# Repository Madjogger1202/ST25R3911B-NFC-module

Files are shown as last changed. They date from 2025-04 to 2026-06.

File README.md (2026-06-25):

# ST25R3911B-NFC-module

**NFC-модуль на высокопроизводительном HF-ридере ST25R3911B с управлением от RP2040 и антенной на плате.**

Плата NFC-ридера на чипе **ST25R3911B** (STMicroelectronics) — это заметно более функциональное решение, чем популярные бюджетные модули (PN532, RC522): высокая выходная мощность, поддержка VHBR, автоматическая подстройка антенны и ёмкостный wake-up. Логику и интерфейс берёт на себя **RP2040**, антенна разведена прямо на плате с соблюдением всех рекомендаций ST по согласующим и фильтрующим цепям. После отладки модуль можно смело переиспользовать как ВЧ-фронтенд в составе больших систем.

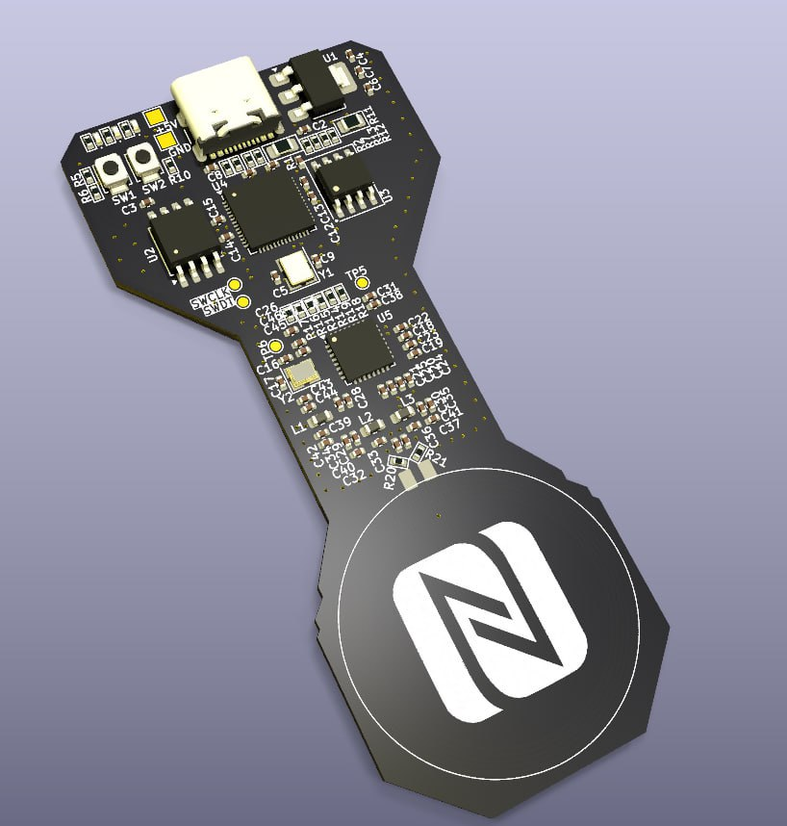
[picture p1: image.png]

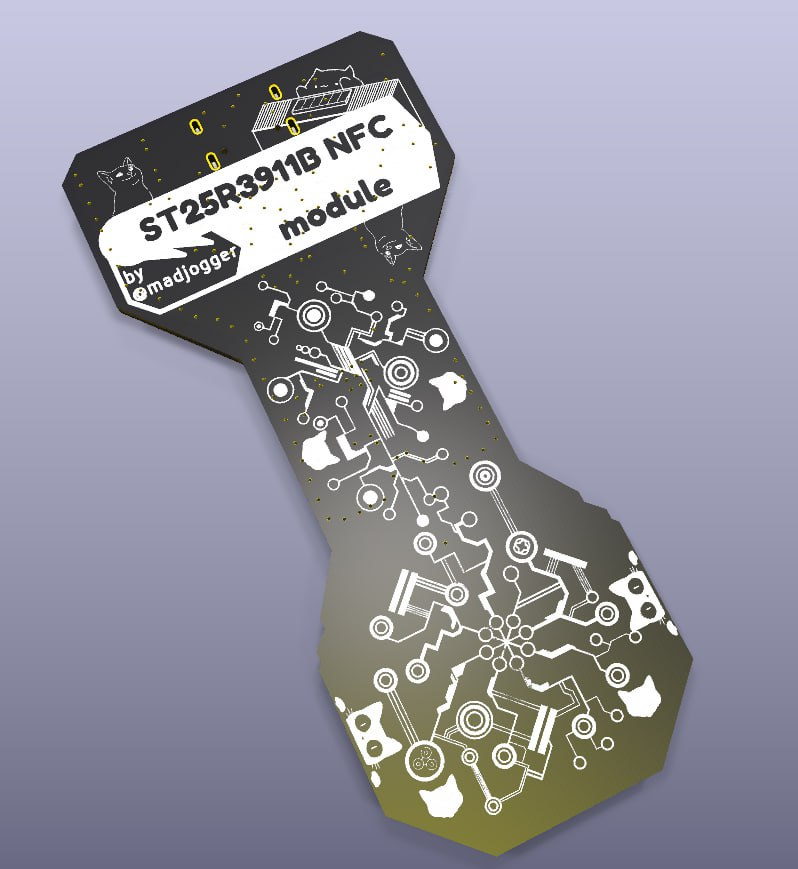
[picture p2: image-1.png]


## Обзор

- **Название проекта:** ST25R3911B-NFC-module
- **Ридер:** STMicroelectronics ST25R3911B — высокопроизводительный HF reader / NFC initiator (13.56 МГц)
- **Микроконтроллер:** Raspberry Pi RP2040
- **Интерфейс ридер ↔ МК:** SPI
- **Антенна:** на плате, с согласующими и фильтрующими цепями по рекомендациям ST
- **Назначение:** отладка ST25R3911B и использование как ВЧ-фронтенда в больших системах

## Ключевые особенности

- **Мультипротокольный HF-ридер** — ISO14443A, ISO14443B (включая высокие битрейты / VHBR), ISO15693, ISO18092 (NFCIP-1, инициатор и активная цель), FeliCa; MIFARE Classic через AFE и framing на стороне МК
- **Высокая выходная мощность** — до 1.4 Вт, два дифференциальных низкоомных (1 Ω) драйвера антенны → большая дальность считывания
- **Автоматическая подстройка антенны (AAT)** — оптимизация под напрямую подключённую антенну
- **Ёмкостный wake-up** — детектирование присутствия карты без включения ВЧ-поля (низкое энергопотребление), плюс детект по амплитуде/фазе
- **Встроенный АЦП** — измерение амплитуды и фазы сигнала на антенне, калибровка
- **Антенна на плате** — разведена с соблюдением рекомендаций ST по фильтрам и согласованию
- **Управление от RP2040** — двухъядерный Cortex-M0+ для логики и обработки

## Что на плате

| Блок | Компонент | Назначение |
|---|---|---|
| NFC-ридер | ST25R3911B | HF reader / NFC initiator, 13.56 МГц |
| Микроконтроллер | RP2040 | Управление, обработка, интерфейс с хостом |
| Антенна | PCB-антенна | Дифференциальная антенна на плате |
| Согласование/фильтры | EMC-фильтр + matching | Цепи по рекомендациям ST (AAT) |
| Интерфейс | USB | Питание и связь с хостом |

## Технические характеристики

| Параметр | Значение |
|---|---|
| Ридер | STMicroelectronics ST25R3911B |
| Рабочая частота | 13.56 МГц |
| Протоколы | ISO14443A/B (+VHBR), ISO15693, ISO18092 (NFCIP-1), FeliCa |
| Выходная мощность | до 1.4 Вт (дифференциальная антенна) |
| Драйверы антенны | 2× дифференциальные, 1 Ω |
| Доп. функции | AAT, ёмкостный wake-up, встроенный АЦП |
| Интерфейс ридера | SPI |
| Микроконтроллер | RP2040, 2× Cortex-M0+ до 133 МГц |
| Питание ридера | 2.4 … 5.5 В |

## Антенна

Антенна выполнена непосредственно на печатной плате. Согласующие и фильтрующие цепи (EMC-фильтр между драйвером и антенной, цепи подстройки) разведены с соблюдением рекомендаций STMicroelectronics, что в связке с автоматической подстройкой антенны (AAT) обеспечивает стабильную работу ВЧ-тракта.

## Применение

- Считыватель карт и меток NFC/RFID (контроль доступа, тикетинг)
- ВЧ-фронтенд для интеграции в большие системы
- Отладка и изучение многопротокольного NFC-ридинга
- Промышленные, медицинские и потребительские NFC-приложения

## Среда разработки

- **Схема и плата:** KiCad
- **Прошивка:** PlatformIO / Arduino / Pico SDK (RP2040), драйвер ST25R3911B (ST RFAL)
- **Документация на компоненты:** datasheet ST25R3911B (ST), RP2040 (Raspberry Pi)

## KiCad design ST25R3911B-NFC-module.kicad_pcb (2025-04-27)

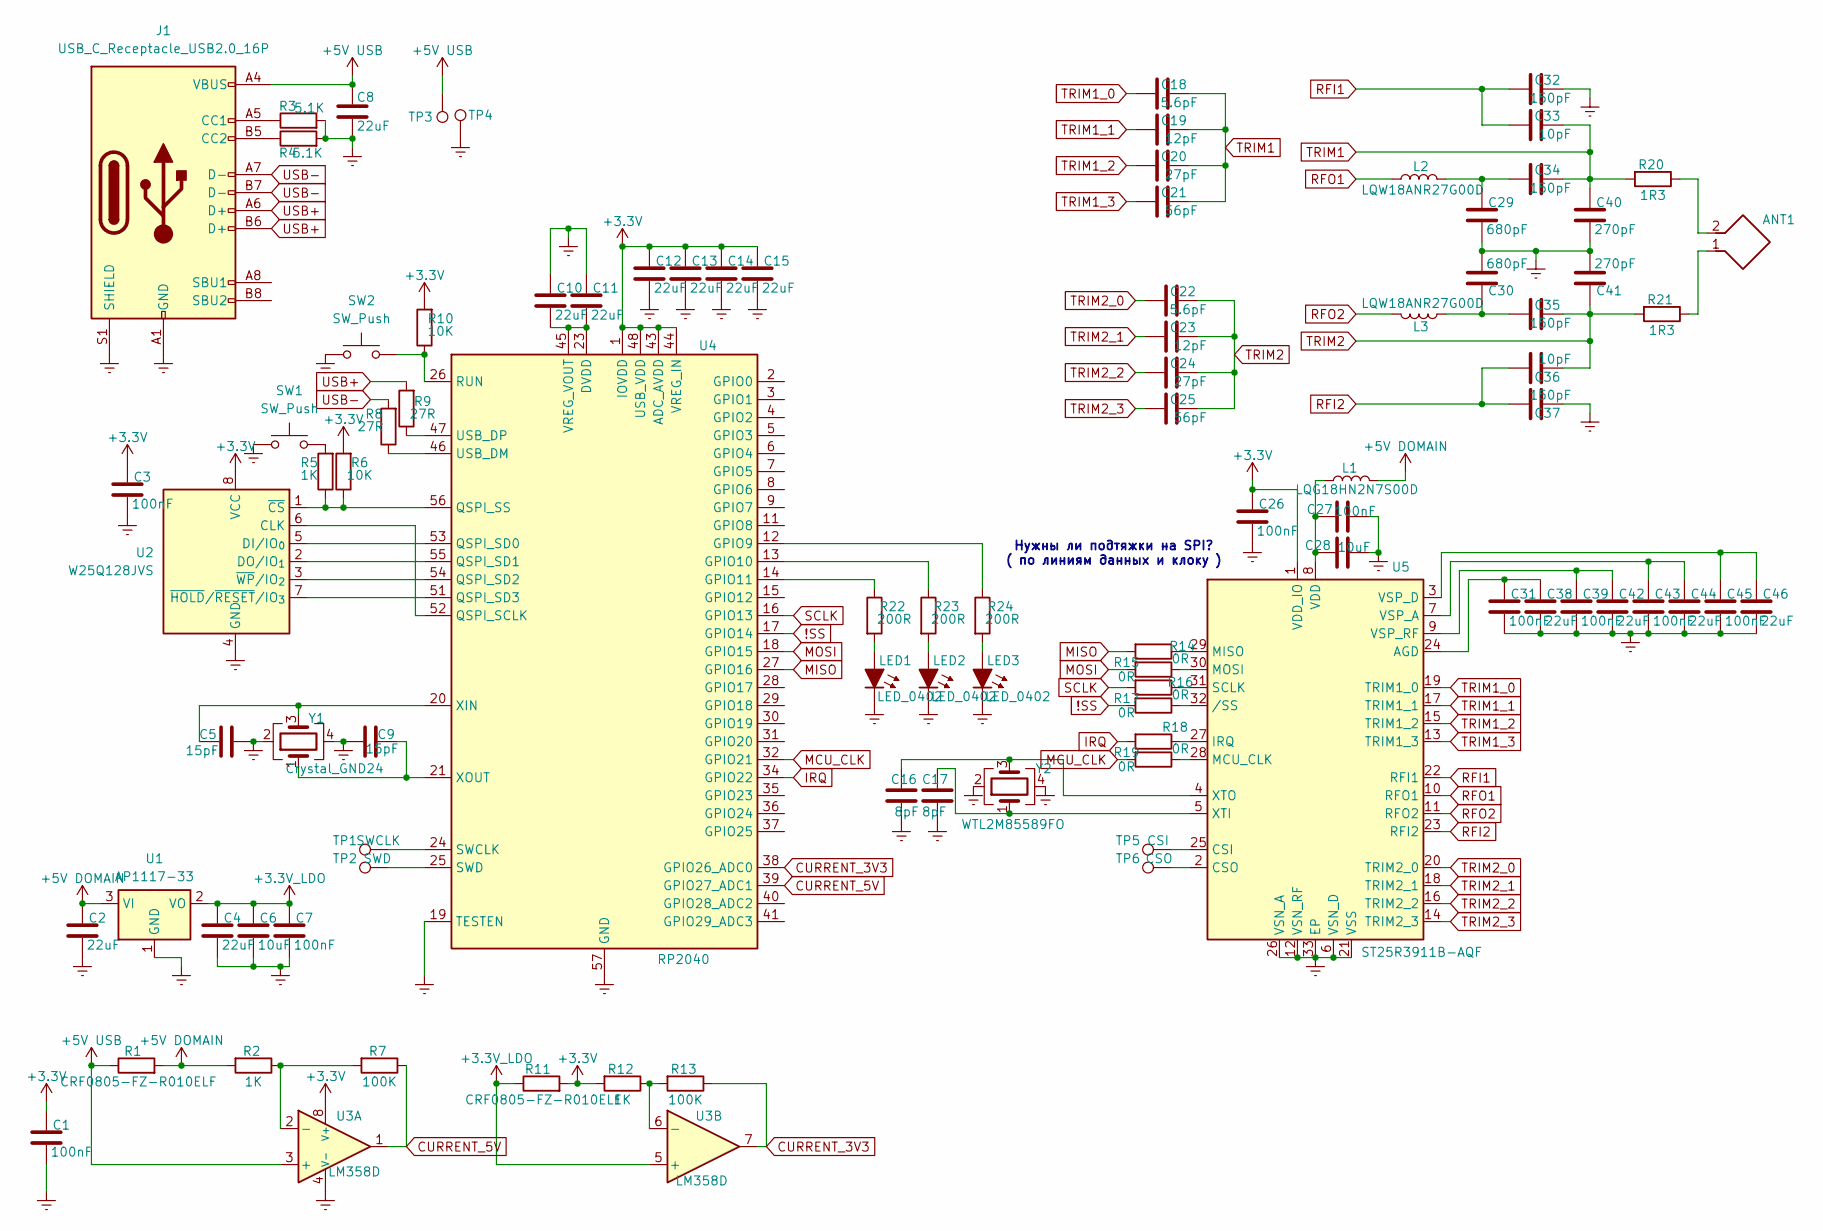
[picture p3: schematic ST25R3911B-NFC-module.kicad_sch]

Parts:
ANT1: Без имени
C1, C3, C7, C26, C27, C31, C39, C43, C45: 100nF; C_0402_1005Metric
C2, C4, C8, C10, C11, C12, C13, C14, C15, C38, C42, C44, C46: 22uF; C_0402_1005Metric
C5, C9: 15pF; C_0402_1005Metric
C6, C28: 10uF; C_0402_1005Metric
C16, C17: 8pF; C_0402_1005Metric
C18, C22: 5.6pF; C_0402_1005Metric
C19, C23: 12pF; C_0402_1005Metric
C20, C24: 27pF; C_0402_1005Metric
C21, C25: 56pF; C_0402_1005Metric
C29, C30: 680pF; C_0402_1005Metric
C32, C34, C35, C37: 150pF; C_0402_1005Metric
C33, C36: 10pF; C_0402_1005Metric
C40, C41: 270pF; C_0402_1005Metric
J1: USB_C_Receptacle_USB2.0_16P; USB_C_Receptacle_GCT_USB4105-xx-A_16P_TopMnt_Horizontal
L1: LQG18HN2N7S00D; L_0603_1608Metric
L2, L3: LQW18ANR27G00D; L_0603_1608Metric
LED1, LED2, LED3: LED_0402; LED_0402_1005Metric
R1: CRF0805-FZ-R010ELF; R_0805_2012Metric_Pad1.15x1.40mm
R2, R5, R12: 1K; R_0402_1005Metric
R3, R4: 5.1K; R_0402_1005Metric
R6, R10: 10K; R_0402_1005Metric
R7, R13: 100K; R_0402_1005Metric
R8, R9: 27R; R_0402_1005Metric
R11: CRF0805-FZ-R010ELF; R_0805_2012Metric
R14, R15, R16, R17, R18, R19: 0R; R_0402_1005Metric
R20, R21: 1R3; R_0402_1005Metric
R22, R23, R24: 200R; R_0402_1005Metric
SW1, SW2: SW_Push; SW_SPST_B3U-1000P
TP1: SWCLK; TestPoint_Pad_D1.0mm
TP2: SWD; TestPoint_Pad_D1.0mm
TP3, TP4: TestPoint_Pad_1.5x1.5mm
TP5: CSI; TestPoint_Pad_D1.0mm
TP6: CSO; TestPoint_Pad_D1.0mm
U1: AP1117-33; SOT-223-3_TabPin2
U2: W25Q128JVS; SOIC-8_5.3x5.3mm_P1.27mm
U3: LM358D; SO-8_3.9x4.9mm_P1.27mm
U4: RP2040; QFN-56-1EP_7x7mm_P0.4mm_EP3.2x3.2mm
U5: ST25R3911B-AQF; QFN-32-1EP_5x5mm_P0.5mm_EP3.6x3.6mm_ThermalVias
Y1: Crystal_GND24; Crystal_SMD_Abracon_ABM8G-4Pin_3.2x2.5mm
Y2: WTL2M85589FO; Crystal_SMD_2520-4Pin_2.5x2.0mm

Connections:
!SS: R17.2, U4.17 (GPIO14)
+3.3V: C1.1, C3.1, C12.1, C13.1, C14.1, C15.1, C26.1, R6.2, R10.2, R11.2, R12.2, U2.8 (VCC), U3.8 (V+), U4.1 (IOVDD), U4.10 (IOVDD), U4.22 (IOVDD), U4.33 (IOVDD), U4.42 (IOVDD), U4.43 (ADC_AVDD), U4.44 (VREG_IN), U4.48 (USB_VDD), U4.49 (IOVDD), U5.1 (VDD_IO)
+3.3V_LDO: C4.1, C6.1, C7.1, R11.1, U1.2 (VO), U3.5 (+)
+5V DOMAIN: C2.1, L1.1, R1.2, R2.2, U1.3 (VI)
+5V USB: C8.1, J1.A4 (VBUS), J1.A9 (VBUS), J1.B4 (VBUS), J1.B9 (VBUS), R1.1, TP3.1, U3.3 (+)
CURRENT_3V3: R13.1, U3.7, U4.38 (GPIO26_ADC0)
CURRENT_5V: R7.1, U3.1, U4.39 (GPIO27_ADC1)
Earth: C1.2, C2.2, C3.2, C4.2, C5.2, C6.2, C7.2, C8.2, C9.1, C10.1, C11.1, C12.2, C13.2, C14.2, C15.2, C16.1, C17.2, C26.2, C27.2, C28.2, C29.2, C30.2, C31.2, C32.2, C37.2, C38.2, C39.2, C40.2, C41.2, C42.2, C43.2, C44.2, C45.2, C46.2, J1.A1 (GND), J1.A12 (GND), J1.B1 (GND), J1.B12 (GND), J1.S1 (SHIELD), LED1.1 (K), LED2.1 (K), LED3.1 (K), R3.2, R4.2, SW1.1, SW2.1, TP4.1, U1.1 (GND), U2.4 (GND), U3.4 (V-), U4.19 (TESTEN), U4.57 (GND), U5.6 (VSN_D), U5.12 (VSN_RF), U5.21 (VSS), U5.26 (VSN_A), U5.33 (EP), Y1.2, Y1.4, Y2.2, Y2.4
IRQ: R18.2, U4.34 (GPIO22)
MCU_CLK: R19.2, U4.32 (GPIO21)
MISO: R14.2, U4.27 (GPIO16)
MOSI: R15.2, U4.18 (GPIO15)
unnamed: ANT1.1, R21.1
unnamed: ANT1.2, R20.1
unnamed: C29.1, C34.1, L2.2
unnamed: C30.1, C35.1, L3.2
unnamed: J1.A5 (CC1), R3.1
unnamed: J1.B5 (CC2), R4.1
unnamed: LED1.2 (A), R22.2
unnamed: LED2.2 (A), R23.2
unnamed: LED3.2 (A), R24.2
unnamed: R5.2, SW1.2
unnamed: U2.6 (CLK), U4.52 (QSPI_SCLK)
unnamed: U2.5 (DI/IO_{0}), U4.53 (QSPI_SD0)
unnamed: U2.2 (DO/IO_{1}), U4.55 (QSPI_SD1)
unnamed: R5.1, R6.1, U2.1 (~CS), U4.56 (QSPI_SS)
unnamed: U2.7 (~HOLD/~RESET/IO_{3}), U4.51 (QSPI_SD3)
unnamed: U2.3 (~WP/IO_{2}), U4.54 (QSPI_SD2)
unnamed: R2.1, R7.2, U3.2 (-)
unnamed: R12.1, R13.2, U3.6 (-)
unnamed: R24.1, U4.12 (GPIO9)
unnamed: R23.1, U4.13 (GPIO10)
unnamed: R22.1, U4.14 (GPIO11)
unnamed: R10.1, SW2.2, U4.26 (RUN)
unnamed: TP1.1, U4.24 (SWCLK)
unnamed: TP2.1, U4.25 (SWD)
unnamed: R8.1, U4.46 (USB_DM)
unnamed: R9.1, U4.47 (USB_DP)
unnamed: C10.2, C11.2, U4.23 (DVDD), U4.45 (VREG_VOUT), U4.50 (DVDD)
unnamed: C5.1, U4.20 (XIN), Y1.3
unnamed: C9.2, U4.21 (XOUT), Y1.1
unnamed: C31.1, C38.1, U5.24 (AGD)
unnamed: TP5.1, U5.25 (CSI)
unnamed: TP6.1, U5.2 (CSO)
unnamed: R18.1, U5.27 (IRQ)
unnamed: R19.1, U5.28 (MCU_CLK)
unnamed: R14.1, U5.29 (MISO)
unnamed: R15.1, U5.30 (MOSI)
unnamed: R16.1, U5.31 (SCLK)
unnamed: C27.1, C28.1, L1.2, U5.8 (VDD)
unnamed: C43.1, C44.1, U5.7 (VSP_A)
unnamed: C45.1, C46.1, U5.3 (VSP_D)
unnamed: C39.1, C42.1, U5.9 (VSP_RF)
unnamed: C17.1, U5.5 (XTI), Y2.1
unnamed: C16.2, U5.4 (XTO), Y2.3
unnamed: R17.1, U5.32 (/SS)
RFI1: C32.1, C33.1, U5.22 (RFI1)
RFI2: C36.1, C37.1, U5.23 (RFI2)
RFO1: L2.1, U5.10 (RFO1)
RFO2: L3.1, U5.11 (RFO2)
SCLK: R16.2, U4.16 (GPIO13)
TRIM1: C18.2, C19.2, C20.2, C21.2, C33.2, C34.2, C40.1, R20.2
TRIM1_0: C18.1, U5.19 (TRIM1_0)
TRIM1_1: C19.1, U5.17 (TRIM1_1)
TRIM1_2: C20.1, U5.15 (TRIM1_2)
TRIM1_3: C21.1, U5.13 (TRIM1_3)
TRIM2: C22.2, C23.2, C24.2, C25.2, C35.2, C36.2, C41.1, R21.2
TRIM2_0: C22.1, U5.20 (TRIM2_0)
TRIM2_1: C23.1, U5.18 (TRIM2_1)
TRIM2_2: C24.1, U5.16 (TRIM2_2)
TRIM2_3: C25.1, U5.14 (TRIM2_3)
USB+: J1.A6 (D+), J1.B6 (D+), R9.2
USB-: J1.A7 (D-), J1.B7 (D-), R8.2

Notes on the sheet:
Нужны ли подтяжки на SPI? ( по линиям данных и клоку )

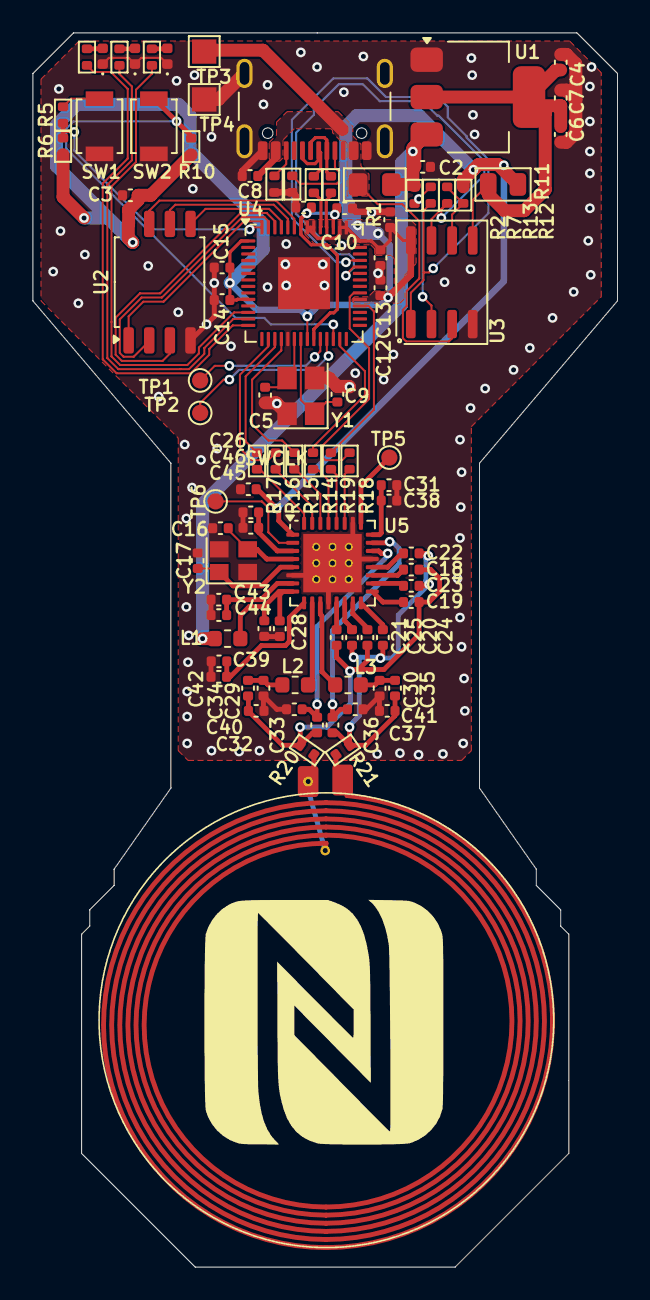
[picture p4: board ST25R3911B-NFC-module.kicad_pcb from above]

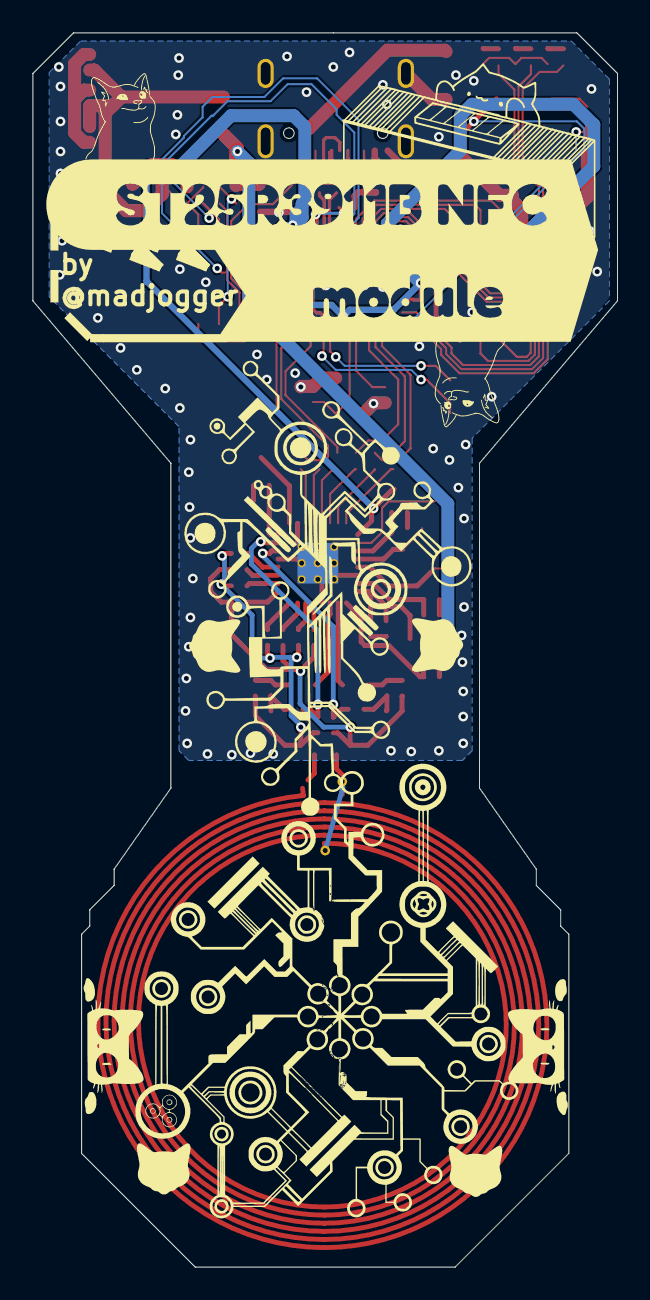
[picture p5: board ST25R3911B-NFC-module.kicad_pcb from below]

Board: 2 copper layers, 36.0 x 76.0 mm, 95 parts (2 on the bottom side), 73 nets.

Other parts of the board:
kibuzzard-680CEA90: G***; kibuzzard-680CEA90
kibuzzard-680CEAEF: G***; kibuzzard-680CEAEF

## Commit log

2025-04-23 тык тык
    [ST25R3911B-NFC-module.kicad_pcb, ST25R3911B-NFC-module.kicad_sch]
2025-04-24 схему вроде сделал, надо только понять как вообще адекватно, а главное симметрично мне провести к антенне всё что надобно
    [ST25R3911B-NFC-module.kicad_pcb, ST25R3911B-NFC-module.kicad_sch]
2025-04-26 rev0 готова
    [ST25R3911B-NFC-module.kicad_pcb, ST25R3911B-NFC-module.kicad_sch]
2025-04-27 Добавлено примечание чтобы быстро разобраться если не заработает
    [ST25R3911B-NFC-module.kicad_sch]
2025-04-27 Довёл соединения для АЦП чтения потребления тока для доменов питания
    [ST25R3911B-NFC-module.kicad_pcb, ST25R3911B-NFC-module.kicad_sch]
